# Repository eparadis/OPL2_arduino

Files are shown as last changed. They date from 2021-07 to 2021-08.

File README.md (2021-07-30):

### OPL2 and Arduino

Inspired by and based largely on [this project](https://hackaday.io/project/18995-opl2-audio-board-for-arduino-raspberry-pi).

This project glues a OPL2 FM synthesis chip by Yamaha to an Aduino Pro Mini. It was originally prototyped on a breadboard with an LCD and controls to allow parameters to be changed.

The goal is to make a eurorack compatible module that balances the flexibility
and simplicity inherent in a multi-voice 2-operator FM synthesis chip like the
YM3812 (OPL2). To this end, some parameters will be controlled by CV while
others will be menu-driven settings.

The prototype explored a variety of polyphonic "chord modes" as well as various
CV-to-operator-parameter mappings. This design should continue to allow that
exploration.

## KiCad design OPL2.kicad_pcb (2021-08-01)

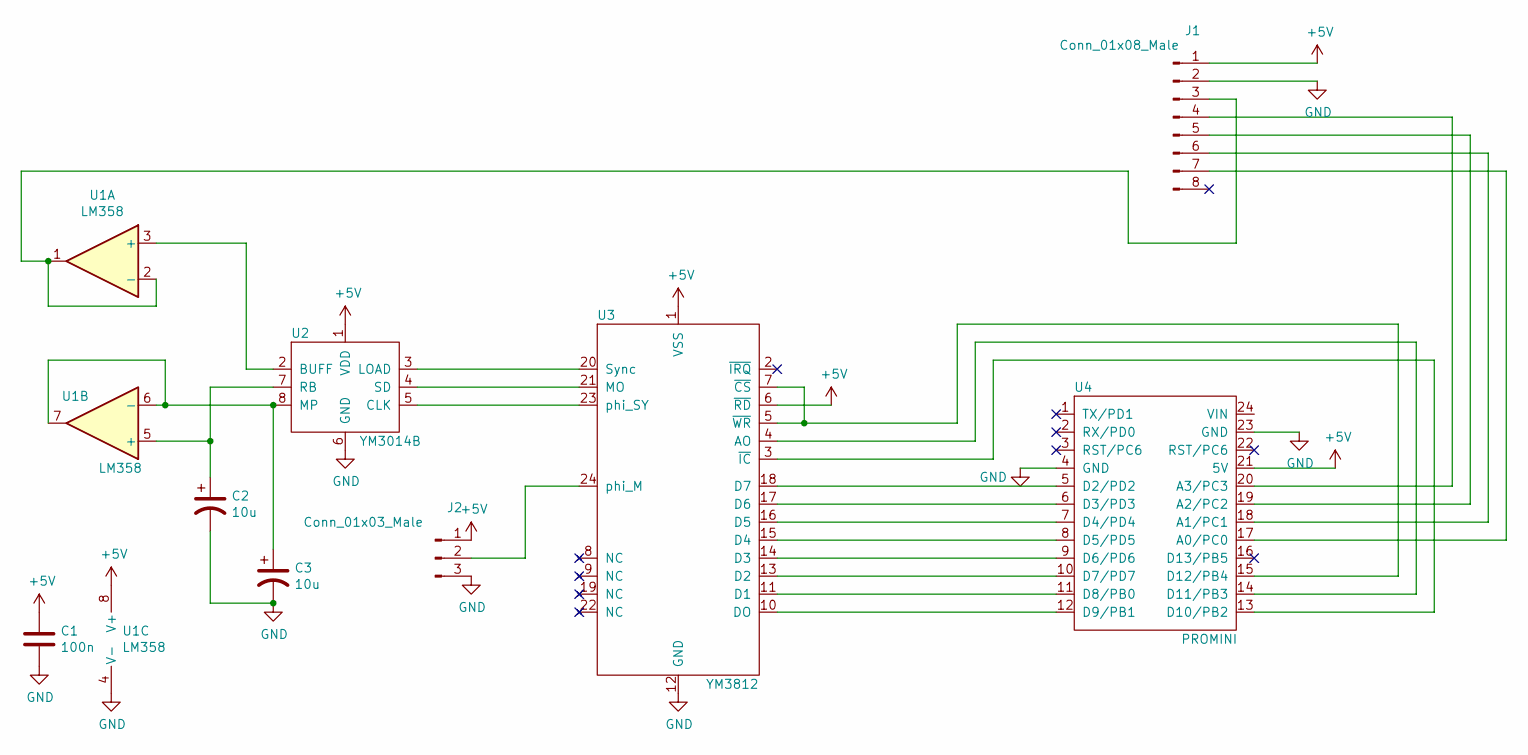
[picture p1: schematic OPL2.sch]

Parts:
C1: 100n; CP_Radial_D7.5mm_P2.50mm
C2, C3: 10u; CP_Radial_D7.5mm_P2.50mm
J1: Conn_01x08_Male; PinHeader_1x08_P2.54mm_Vertical
J2: Conn_01x03_Male; PinHeader_1x03_P2.54mm_Vertical
U1: LM358; DIP-8_W7.62mm_LongPads
U2: YM3014B; DIP-8_W7.62mm_LongPads
U3: YM3812; DIP-24_W15.24mm_LongPads
U4: PROMINI; DIP-24_W15.24mm_LongPads

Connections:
+5V: C1.1, J1.1, J2.1, U1.8 (V+), U2.1 (VDD), U3.1 (VSS), U3.6 (~RD), U4.21 (5V)
GND: C1.2, C2.2, C3.2, J1.2, J2.3, U1.4 (V-), U2.6 (GND), U3.12 (GND), U4.4 (GND), U4.23 (GND)
unnamed: C2.1, U1.5 (+), U2.7 (RB)
unnamed: C3.1, U1.6 (-), U1.7, U2.8 (MP)
unnamed: J1.3, U1.1, U1.2 (-)
unnamed: J1.4, U4.20 (A3/PC3)
unnamed: J1.5, U4.19 (A2/PC2)
unnamed: J1.6, U4.18 (A1/PC1)
unnamed: J1.7, U4.17 (A0/PC0)
unnamed: J2.2, U3.24 (phi_M)
unnamed: U1.3 (+), U2.2 (BUFF)
unnamed: U2.3 (LOAD), U3.20 (Sync)
unnamed: U2.4 (SD), U3.21 (MO)
unnamed: U2.5 (CLK), U3.23 (phi_SY)
unnamed: U3.3 (~IC), U4.13 (D10/PB2)
unnamed: U3.4 (AO), U4.14 (D11/PB3)
unnamed: U3.5 (~WR), U3.7 (~CS), U4.15 (D12/PB4)
unnamed: U3.10 (DO), U4.12 (D9/PB1)
unnamed: U3.11 (D1), U4.11 (D8/PB0)
unnamed: U3.13 (D2), U4.10 (D7/PD7)
unnamed: U3.14 (D3), U4.9 (D6/PD6)
unnamed: U3.15 (D4), U4.8 (D5/PD5)
unnamed: U3.16 (D5), U4.7 (D4/PD4)
unnamed: U3.17 (D6), U4.6 (D3/PD3)
unnamed: U3.18 (D7), U4.5 (D2/PD2)

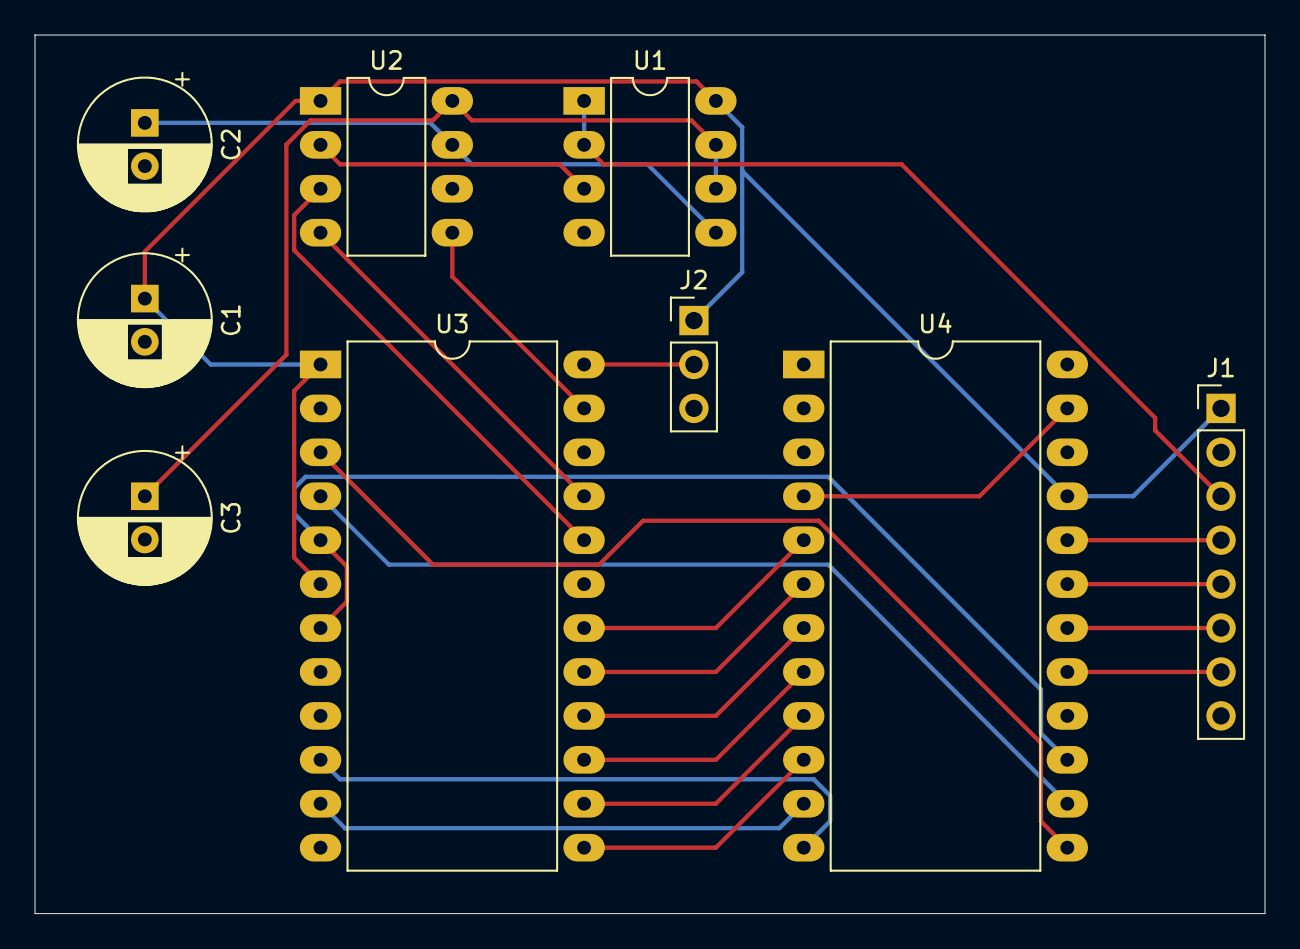
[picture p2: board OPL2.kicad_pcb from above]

Board: 2 copper layers, 71.1 x 50.8 mm, 9 parts (0 on the bottom side), 25 nets.

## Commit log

2021-07-30 github kicad gitignore
2021-07-30 initial commit. everything but the clock generator
    [OPL2.kicad_pcb, OPL2.sch]
2021-08-01 add footprints to everything; add header for clock subcircuit
    [OPL2.kicad_pcb, OPL2.sch]
